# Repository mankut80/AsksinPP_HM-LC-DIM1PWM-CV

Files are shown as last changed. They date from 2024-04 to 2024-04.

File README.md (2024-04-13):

# AsksinPP_HM-LC-DIM1PWM-CV
12V PWM-Dimmer auf AsksinPP-Basis

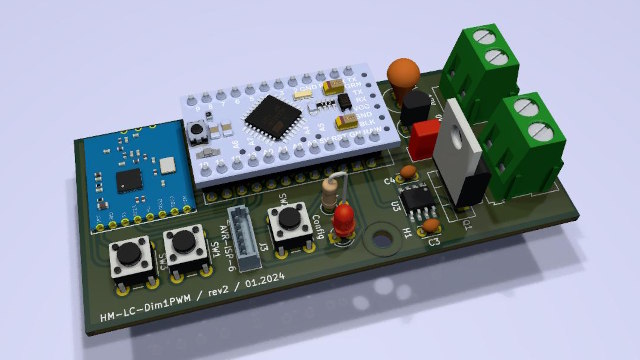
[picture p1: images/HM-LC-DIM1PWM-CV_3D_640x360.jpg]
3D-Ansicht


eine modifizierte Version des 7-24V-Dimmers von psi (Danke dafür :-)).
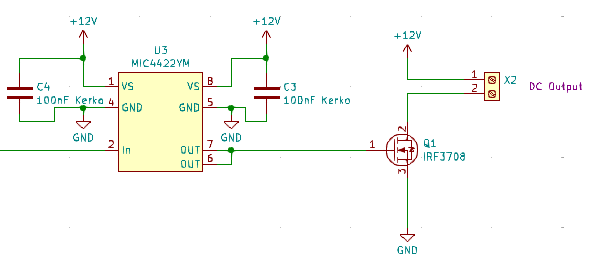
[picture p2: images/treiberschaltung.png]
Treiberschaltung mit MIC4422


Die große Neuerung hier ist der MOSFET-Treiber MIC4422. Wärmeverluste gehören damit der Vergangenheit an, der MOSFET bleibt lauwarm bis kalt. Der Nachteil ist die Tatsache, dass man um eine geätzte Platine nicht herumkommt. Schuld trägt besagter Treiber in der SMD-Variante.

Der zu verwendende MOSFET ist fast egal, Hauptsache er ist vom Typ "N-Kanal". Ein möglichst niedriger Rds-On-Wert (Durchlasswiderstand im eingeschalteten Zustand) ist wünschenswert. 
Ein typischer N-Kanal-MOSFET alter Bauart ist der BUZ11 mit einem Rds von 0,04 Ohm. 
Bei ihm beträgt der Leistungsverlust bei 6A: 6x6x0,04=1.5W. Das ist immer noch ohne Kühlkörper machbar. Besser ist natürlich der IRLB3036 mit einem Rds von 2,4mOhm, da kommt als Wärmeleistung 90mW heraus. Das ist quasi nichts. Die Umschaltverluste kommen da noch oben drauf, die sind aber vernachlässigbar.

Vorsicht!
Die höchste, zulässige Eingangsspannung ist 18V. 24V-LED-Bänder scheiden damit leider aus.

### Gehäuse
Das Gehäuse wird mit einer einzigen Schraube verschlossen. Im CAD-Verzeichnis liegen die passenden step-Dateien und das Original im FreeCAD-Format.
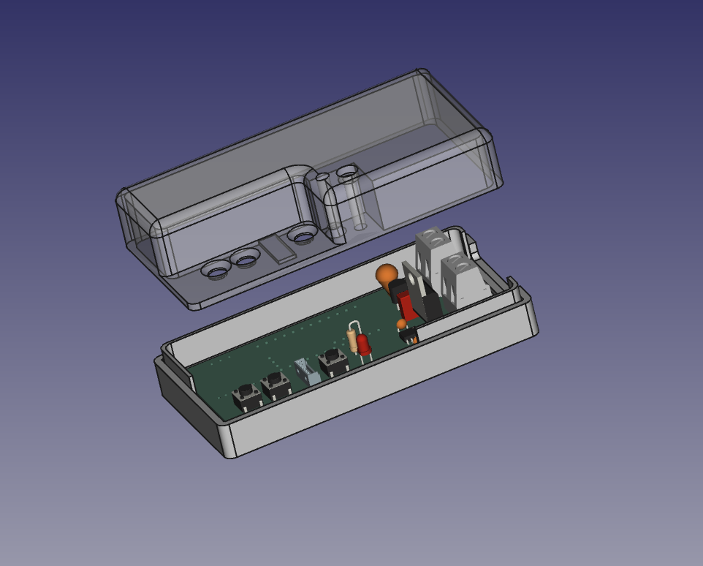
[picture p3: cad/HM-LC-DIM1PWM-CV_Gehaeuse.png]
Gehäuse


### Sketch
Im Sketch müssen die üblichen Anpassungen der Serial usw. vorgenommen werden. Ansonsten enspricht es genau der Version von psi.

### Bauteilliste
| Pos | Ref | Wert |
|-----|-----|---|
| 1 | C3, C4 | 100nF / Keramikkondensator, RM2.5 |
| 2 | C1 | 100µF / 25V D=6mm |
| 3	|	C2 | 100nF	C_Rect_L4.6mm_W3.0mm_P2.50mm_MKS02_FKP02 |
| 4	|	R1 | 330R, 0207 |
| 5	|	D1 | LED	3mm, Farbe egal |
| 6 |	U1 | L78L05, TO92 |
| 7	|	U2 | CC1101-Modul |
| 8 | U3 | MIC4422YM	SOIC-8 |
| 9 |	X1, X2 | Schraubklemme 2pol P5.00mm oder 5.08mm	|
| 10 | SW1 | Taster 6x6mm H5mm |
| 11 | SW2 | Taster 6x6mmm H5mm |
| 12 | A1	| Arduino Pro_Mini |
| 13 | Q1	| IRF3708 oder anderer N-Kanal MOSFET, TO-220 |
| 14 | J3	| AVR-ISP-6	Molex_PicoBlade_53047-0610_1x06_P1.25mm_Vertical |

Position 14 kann bedenkenlos weggelassen werden wenn man nicht per ISP programmieren möchte

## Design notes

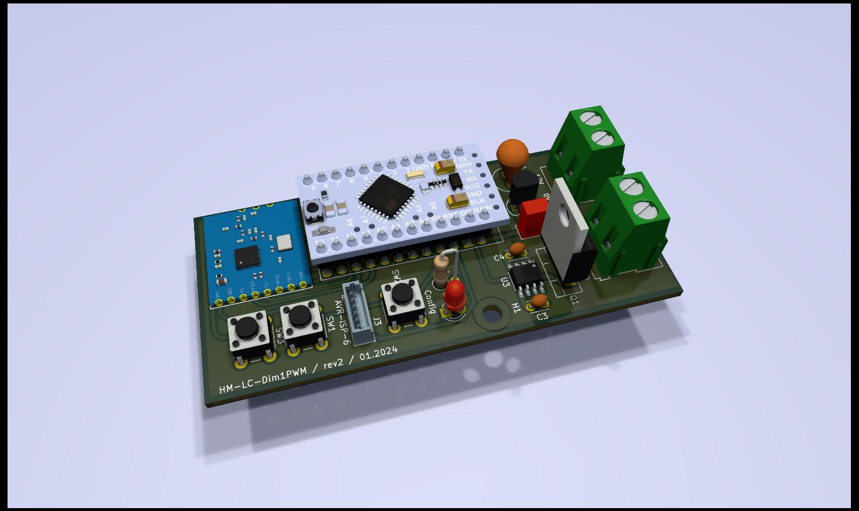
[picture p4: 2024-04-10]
pcb/HM-LC-DIM1PWM-CV_3D.jpg

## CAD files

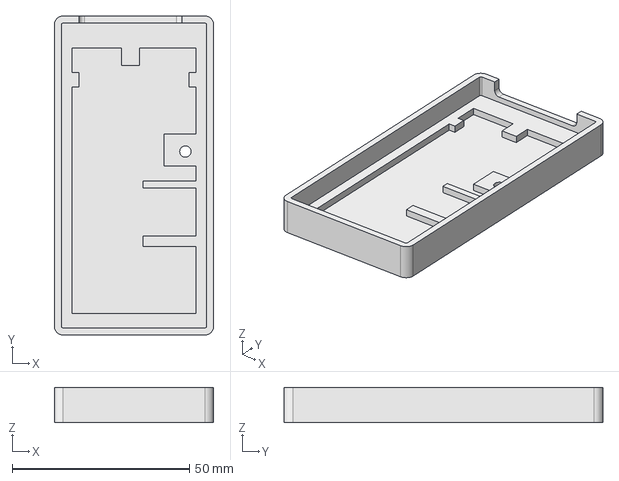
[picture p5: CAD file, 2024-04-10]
cad/HM_AsksinPP_Dimmergehaeuse-Boden.step
45.0 x 90.0 x 10.0 mm

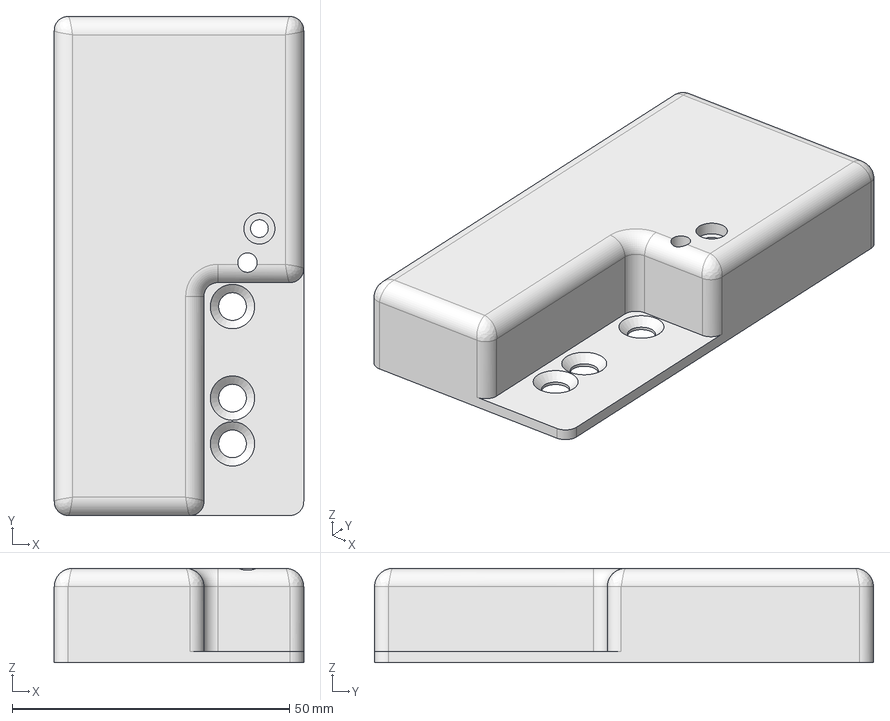
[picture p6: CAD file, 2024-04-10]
cad/HM_AsksinPP_Dimmergehaeuse-Deckel.step
45.0 x 90.0 x 17.0 mm

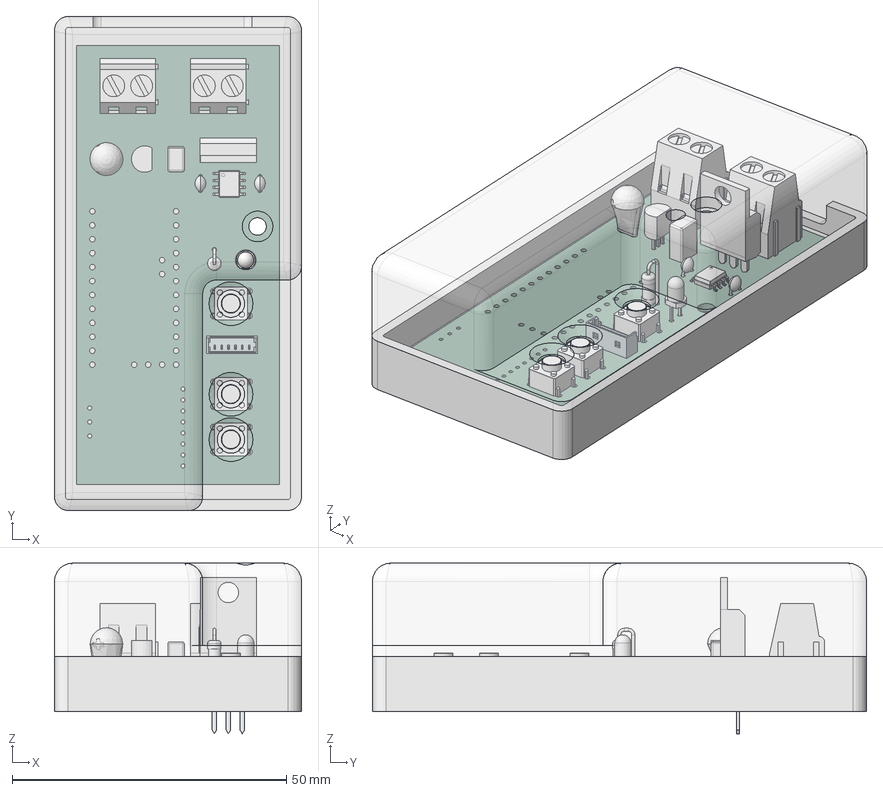
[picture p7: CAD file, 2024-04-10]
cad/HM_AsksinPP_Dimmergehaeuse.FCStd
45.0 x 90.0 x 31.1 mm
Homematic_AsksinPP_PWM_Dimmer PCB
Boden
Deckel

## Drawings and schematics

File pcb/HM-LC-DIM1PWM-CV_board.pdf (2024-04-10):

12V | 0V | LOAD | HM⁻LC⁻Dim¹PWM / rev2 / 01.2024 Config
U3 X2 | LED

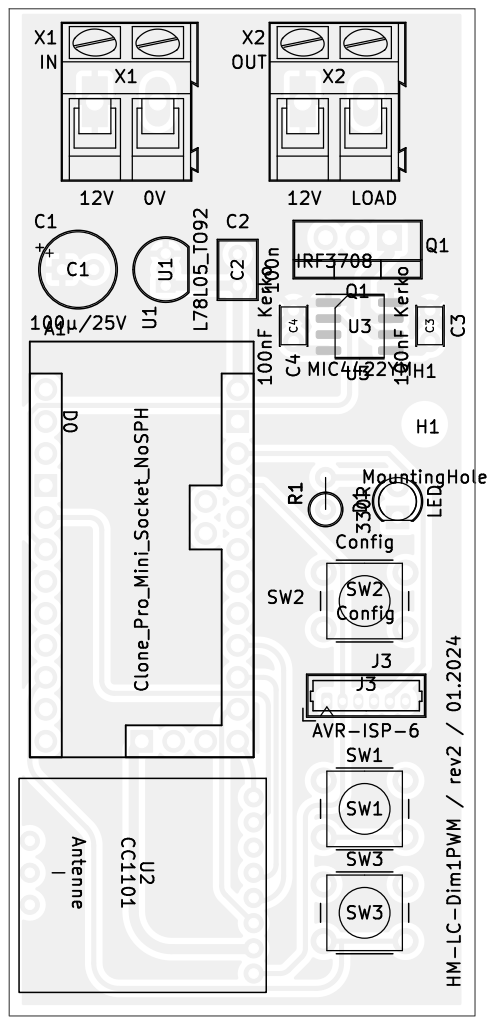
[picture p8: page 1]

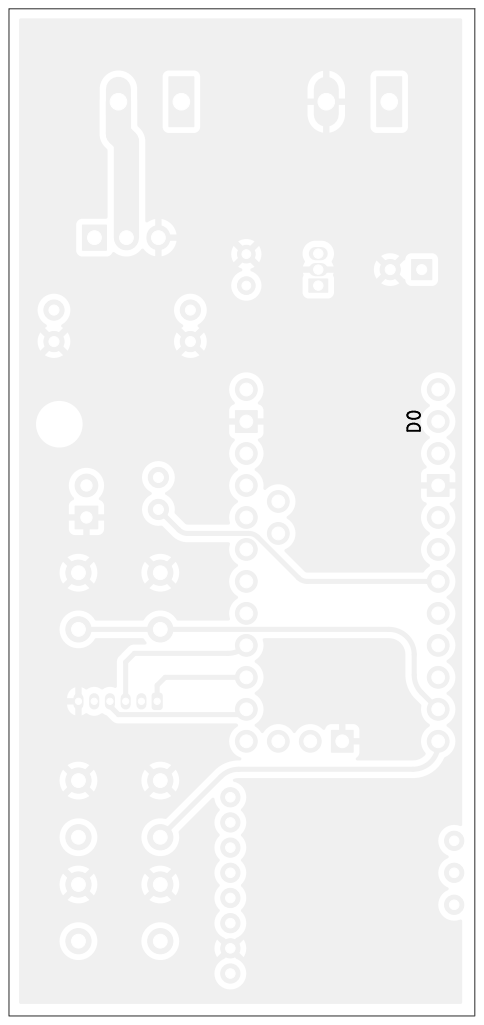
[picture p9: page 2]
D Date: KiCad; E.D.A. 8.0.1 Size: A4; Rev:

Id: 1/1 Title: File: Homematic_AsksinPP_PWM_Dimmer.kicad_pcb Sheet:

33,0000 | mm | 47,0000 mm
12V | 0V | LOAD | HM⁻LC⁻Dim¹PWM / rev2 / 01.2024 Config

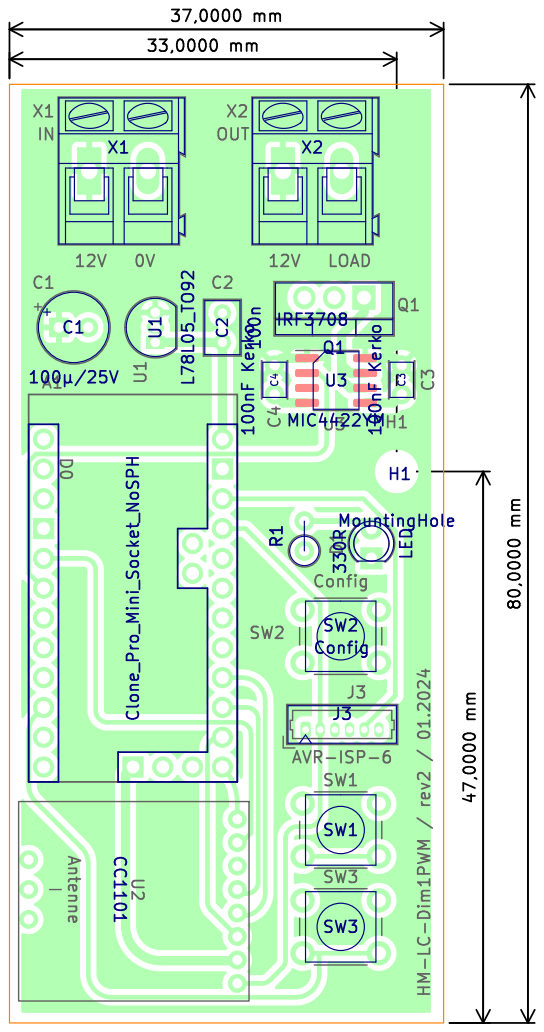
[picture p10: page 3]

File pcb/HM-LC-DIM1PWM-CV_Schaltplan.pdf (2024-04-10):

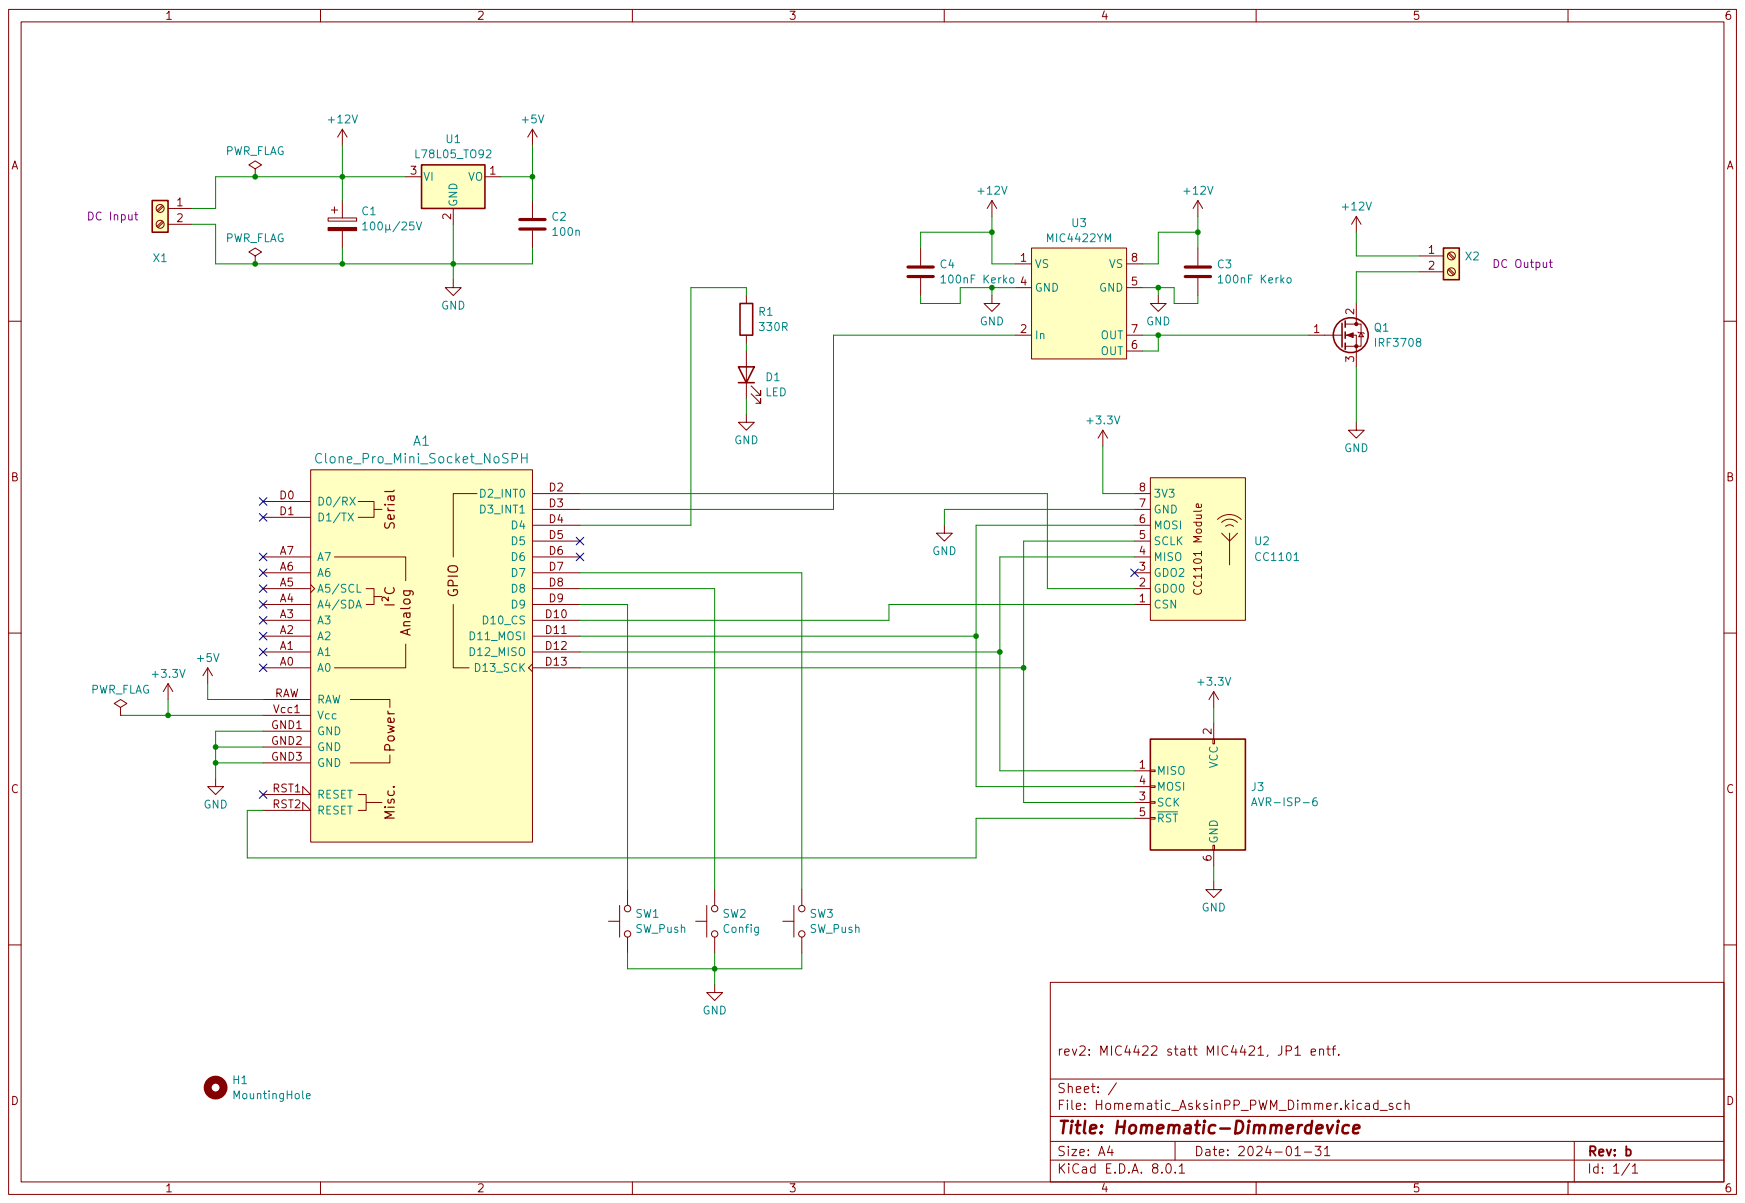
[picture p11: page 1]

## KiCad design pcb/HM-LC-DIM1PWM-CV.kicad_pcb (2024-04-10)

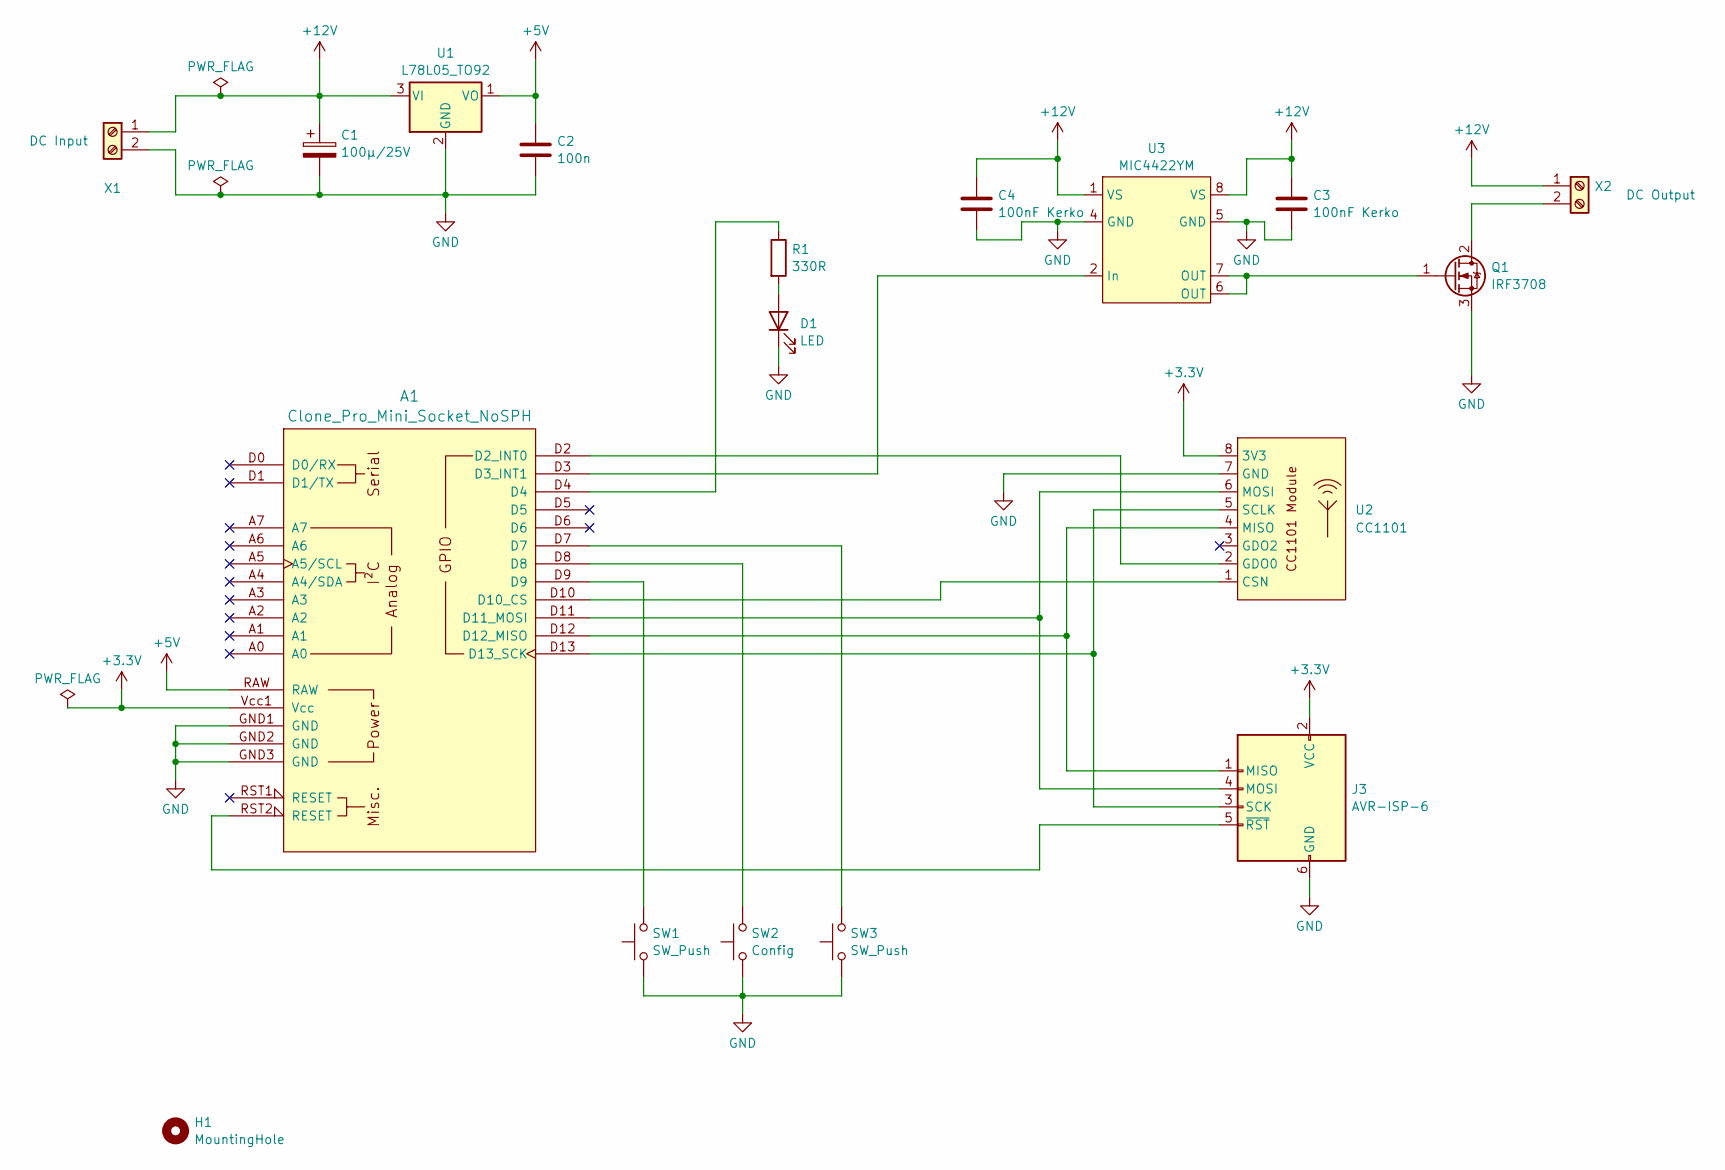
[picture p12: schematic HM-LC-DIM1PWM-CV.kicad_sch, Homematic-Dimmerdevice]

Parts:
A1: Clone_Pro_Mini_Socket_NoSPH
C1: 100µ/25V; CP_Radial_Tantal_D6.0mm_P2.50mm
C2: 100n; C_Rect_L4.6mm_W3.0mm_P2.50mm_MKS02_FKP02
C3, C4: 100nF Kerko; C_Disc_D3.0mm_W2.0mm_P2.50mm
D1: LED; LED_D3.0mm
H1: MountingHole; MountingHole_3.2mm_M3
J3: AVR-ISP-6; Molex_PicoBlade_53047-0610_1x06_P1.25mm_Vertical
Q1: IRF3708; TO-220-3_Vertical
R1: 330R; R_Axial_DIN0207_L6.3mm_D2.5mm_P2.54mm_Vertical
SW1, SW3: SW_Push; SW_PUSH_6mm_H5mm
SW2: Config; SW_PUSH_6mm_H5mm
U1: L78L05_TO92; TO-92_Inline
U2: CC1101; CC1101_Module_v1
U3: MIC4422YM; SOIC-8_3.9x4.9mm_P1.27mm
X1, X2: Screw_Terminal_01x02; TerminalBlock_Altech_AK300-2_P5.00mm

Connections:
+3.3V: A1.Vcc1 (Vcc), J3.2 (VCC), U2.8 (3V3)
+5V: A1.RAW, C2.1, U1.1 (VO)
+12V: C1.1, C3.1, C4.1, U1.3 (VI), U3.1 (VS), U3.8 (VS), X1.1, X2.1
GND: A1.GND1 (GND), A1.GND2 (GND), A1.GND3 (GND), C1.2, C2.2, C3.2, C4.2, D1.1 (K), J3.6 (GND), Q1.3 (S), SW1.1, SW2.1, SW3.1, U1.2 (GND), U2.7 (GND), U3.4 (GND), U3.5 (GND), X1.2
unnamed: A1.D2 (D2_INT0), U2.2 (GDO0)
unnamed: A1.D3 (D3_INT1), U3.2 (In)
unnamed: A1.D10 (D10_CS), U2.1 (CSN)
unnamed: A1.D11 (D11_MOSI), J3.4 (MOSI), U2.6 (MOSI)
unnamed: A1.D12 (D12_MISO), J3.1 (MISO), U2.4 (MISO)
unnamed: A1.D13 (D13_SCK), J3.3 (SCK), U2.5 (SCLK)
unnamed: A1.D4, R1.1
unnamed: A1.D7, SW3.2
unnamed: A1.D8, SW2.2
unnamed: A1.D9, SW1.2
unnamed: D1.2 (A), R1.2
unnamed: A1.RST2 (RESET), J3.5 (~RST)
unnamed: Q1.2 (D), X2.2
unnamed: Q1.1 (G), U3.6 (OUT), U3.7 (OUT)

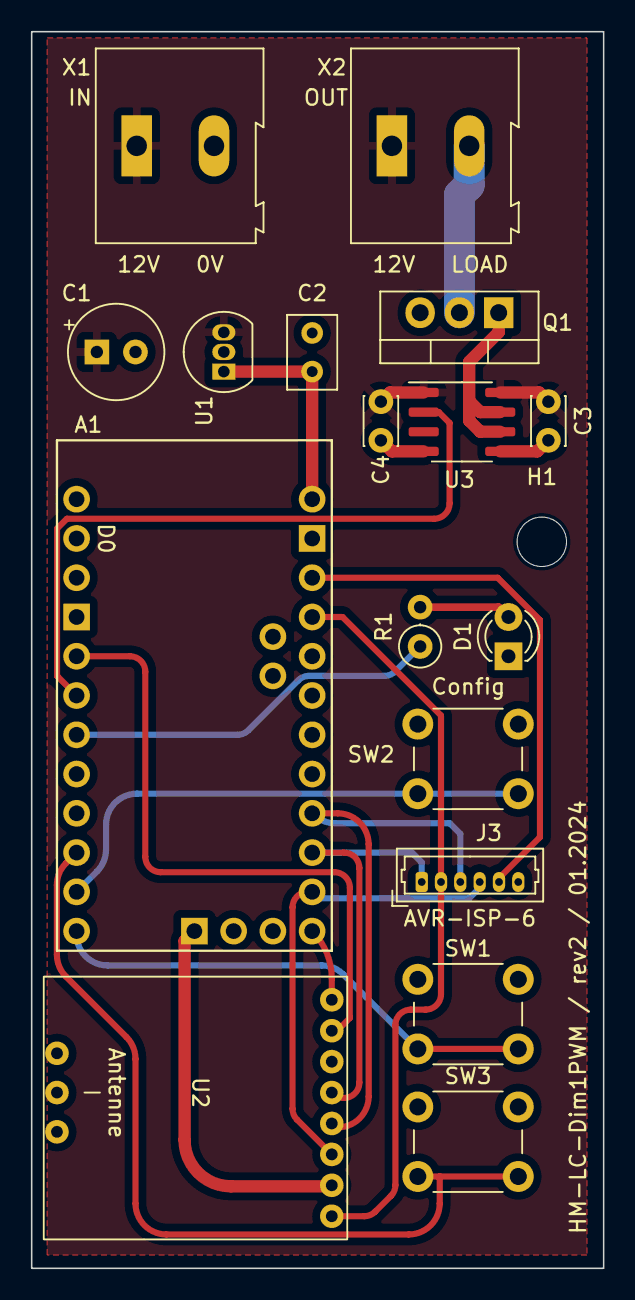
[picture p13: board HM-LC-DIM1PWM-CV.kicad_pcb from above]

Board: 2 copper layers, 37.0 x 80.0 mm, 18 parts (0 on the bottom side), 18 nets.

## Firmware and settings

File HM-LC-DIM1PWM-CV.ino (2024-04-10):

//HM_AsksinPP_PWM_Dimmer 12V/6A


//- -----------------------------------------------------------------------------------------------------------------------
// AskSin++
// 2016-10-31 papa Creative Commons - http://creativecommons.org/licenses/by-nc-sa/3.0/de/
//- -----------------------------------------------------------------------------------------------------------------------

// define this to read the device id, serial and device type from bootloader section
// #define USE_OTA_BOOTLOADER

#define EI_NOTEXTERNAL
//#include <Arduino.h>
#include <EnableInterrupt.h>
#include <AskSinPP.h>
//#include <LowPower.h>

#include <Dimmer.h>


// We use a Pro Mini
// PIN for Status LED
#define LED_PIN 4
// PIN for ConfigToggleButton
#define CONFIG_BUTTON_PIN 8
// PIN for LED MOSFET
#define DIMMER_PIN 3
// PINs for external Buttons
#define BTN1_PIN 7
#define BTN2_PIN 9

//#define PWM_INVERSE true

// number of available peers per channel
#define PEERS_PER_CHANNEL 4

// all library classes are placed in the namespace 'as'
using namespace as;

// define all device properties
const struct DeviceInfo PROGMEM devinfo = {
    {0x10,0x12,0x21},       // Device ID
    "mankutHM01",           // Device Serial
    {0x00,0x67},            // Device Model
    0x29,                   // Firmware Version
    as::DeviceType::Dimmer, // Device Type
    {0x01,0x00}             // Info Bytes
};

/**
 * Configure the used hardware
 */
typedef AvrSPI<10,11,12,13> SPIType;
//typedef AvrSPI<5,11,12,13> SPIType; //ChipSelect auf 5 statt 10
typedef Radio<SPIType,2> RadioType;
typedef StatusLed<LED_PIN> LedType;
typedef AskSin<LedType,NoBattery,RadioType> HalType;
typedef DimmerChannel<HalType,PEERS_PER_CHANNEL> ChannelType;
typedef DimmerDevice<HalType,ChannelType,3,3> DimmerType;

HalType hal;
DimmerType sdev(devinfo,0x20);
DimmerControl<HalType,DimmerType,PWM8<> > control(sdev);
ConfigToggleButton<DimmerType> cfgBtn(sdev);
InternalButton<DimmerType> btn1(sdev, 4);
InternalButton<DimmerType> btn2(sdev, 5);

void setup () {

  DINIT(57600,ASKSIN_PLUS_PLUS_IDENTIFIER);

  if( control.init(hal,DIMMER_PIN) ) {
    // first init - setup connection between buttons and first channel
    sdev.channel(1).peer(cfgBtn.peer());
    sdev.channel(1).peer(btn1.peer());
    sdev.channel(1).peer(btn2.peer());
  }

  // Init the hw buttons
  buttonISR(cfgBtn,CONFIG_BUTTON_PIN);
  buttonISR(btn1, BTN1_PIN);
  buttonISR(btn2, BTN2_PIN);

  sdev.initDone();
  
  // Output ID and Serial in serial console
  DDEVINFO(sdev);
}

void loop() {
  hal.runready();
  sdev.pollRadio();
}
